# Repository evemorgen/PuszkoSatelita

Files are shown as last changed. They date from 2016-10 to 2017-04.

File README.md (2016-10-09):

# To jest repo w którym trzymamy wszystkie pliki zwiącane z projektem CanSat #

## Struktura organizacyjna: ##
1. dokumentacja
    - folder *dokumentacja* służy do trzymania dokumentacji projektu, kolejnych jej iteracji, oraz ostatecznych wersji na PDR, CDE, FDR
2. code
    - folder *code* służy do trzymania jakiegokolwiek kodu, czy to arduino czy coś co będzie obrabiać dane potem itd.
3. elektronika
    - folder *elektronika* służy do trzymania schematów eagle dla projektu, ewentualnie innych dziwnych rzeczy związanych z elektroniką.

## Media społecznościowe ##
  * [Facebook](https://www.facebook.com/JJCanSatTeam/)

  * [WordPress](https://jjcansat.wordpress.com)

And remember, before asking     
<p align="center">
    
</p>

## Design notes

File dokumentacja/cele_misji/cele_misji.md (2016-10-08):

## Cel podstawowy
  - Mierzenie temperatury i ciśnienia oraz wnioskowanie wysokości na podstawie pomiarów.

## Cele dodatkowe
  - Zebranie i przetworzenie informacji na temat warunków do lądowania ciężkiego lądownika na badanym obszarze.

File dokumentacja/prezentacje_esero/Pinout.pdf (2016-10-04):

Mapa wyjść komputera pokładowego Arduino Pro Micro

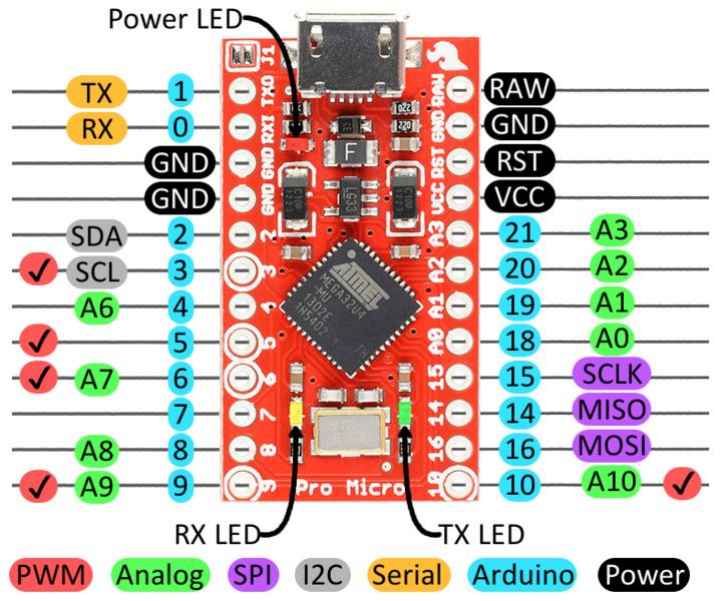
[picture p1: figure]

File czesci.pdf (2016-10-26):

CZĘŚĆ | CENA | Link | UWAGI
Rasberry Pi Zero | 10Phound ~ 50zł + 5phound wysyłka | https://thepihut.com/products/raspberry-pi-zero
Termometr | 23,9 | https://botland.com.pl/czujniki-temperatury/3144-czujnik-temperatury-wysokiej-precyzji-mcp9808-i2c-modul-adafruit.html
Enkoder optyczny (czujnik prędkości wiatru) | 29,9 | https://botland.com.pl/enkodery/1878-zestaw-enkoderow-optycznych-do-micro-silnikow-pololu-wersja-33v.html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
Pololu AltlMU-10 v5 | 89,9 | https://botland.com.pl/czujniki-9dof-imu/5728-pololu-altimu-10-v5-zyroskop-akcelerometr-kompas-i-wysokosciomierz-i2c-3-5v.html
Waveshare IMU 10DoF | 64 | https://botland.com.pl/czujniki-9dof-imu/4655-waveshare-imu-10dof-mpu9255-bmp180-3-osiowy-akcelerometr-zyroskop-i-magnetometr-oraz-barometr.html
GPS | 197 | https://botland.com.pl/moduly-gps/1691-odbiornik-gps-venus-ze-zlaczem-sma-sparkfun.html
Antena do GPS | 57 | https://botland.com.pl/anteny/2315-antena-gps-embedded-ze-zlaczem-sma.html?search_query=gps+antena&results=25
Kamera Pi zero | 135 | http://allegro.pl/wawa-kamera-v2-8mpx-do-wyboru-do-raspberry-pi-3b-i6304136630.html
Baterie Li-Ion | 103,6 | https://botland.com.pl/akumulatory-li-ion/5658-ogniwo-18650-li-ion-panasonic-ncr-18650b-3400mah.html
Przetwornica 3.3V | 47,8 | https://botland.com.pl/przetwornice-impulsowe/1427-przetwornica-step-up-step-down-s7v8f3-5v-1a.html
Elementy pasywne (filtracja) | ~10 | pojedyńczo w sklepach
Radio RF | $12.72 | http://www.ebay.com/itm/331962516696

Stacja bazowa
Arduino Uno Rev3 (wstawiam orginał) | 95 | https://botland.com.pl/arduino-moduly-glowne/1060-arduino-uno-r3.html
Radio RF | $12.72 | http://www.ebay.com/itm/331962516696
Antena Yagi | 152 | http://allegro.pl/antena-lte-800-1800-mhz-b315-b593-zte-d-link-sma-i5985534928.html
moduł microSD | 14,9 | https://botland.com.pl/akcesoria-do-kart-pamieci/5631-modul-czytnika-kart-microsd-waveshare.html
kabel do kompa | 4,19 | https://nettigo.pl/products/kabel-usb-a-b?utm_campaign=all_akademia&utm_medium=link&utm_source=mcart
kabel do anteny | 10 m w zestawie z anteną | http://allegro.pl/antena-lte-800-1800-mhz-b315-b593-zte-d-link-sma-i5985534928.html

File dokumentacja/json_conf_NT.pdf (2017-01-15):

# JJ CanSat Team Base Station JSON protocol

## "Message type" : (String)

Indicates what is in the frame.
- "STANDARD_DATA" – standarized sensors measurements.
- "ERROR" : - information about error.
- "CONF_REQUEST" – message aimed to obtain configuration data.

## Standard data

- "TEMP_CAN" : Temperature measured by CanSat. (Float)
- "TEMP_BASE" : Temperature measured by Base Station. (Float)
- "PRESS_CAN" : Pressure measured by CanSat. (Float)
- "PRESS_BASE" : Pressure measured by Base Station. (Float)
- "X_ROT" : X axis CanSat rotation. (Float)
- "Y_ROT" : Y axis CanSat rotation. (Float)
- "Z_ROT" : Z axis CanSat rotation. (Float)
- "ALT_BASE" : Altitude measured by Base Station. (Float)
- "GPS_N" : N GPS CanSat cordinate. (Float)
- "GPS_E" : E GPS CanSat cordinate. (Float)
- "WIND_SPEED": Wind speed measured by CanSat. (Float)
- "AIR_HUM": Air humidity measured by CanSat. (Float)

## Error

- "ERROR_TYPE" : Information about occured error. (String)

## Example frame

{
"Message type" : "STANDARD_DATA", "TEMP_CAN" :1,
"TEMP_BASE" : 1,
"PRESS_CAN" : 1,
"PRESS_BASE" :1,
"X_ROT" : 1,
"Y_ROT" : 1,
"Z_ROT" :1,
"ALT_BASE" :1,
"GPS_N" : 1,
"GPS_E" : 1,
"WIND_SPEED": 1,
"AIR_HUM": 1
}

{
"Message type" : "ERROR",
"ERROR_TYPE" : "SDCARD_ERROR" }

{
"Message type" : "CONF_REQUEST" }

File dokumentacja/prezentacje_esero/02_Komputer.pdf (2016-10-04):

## I sesja technologiczna

# Komputer pokładowy

WARSZTATY CANSAT

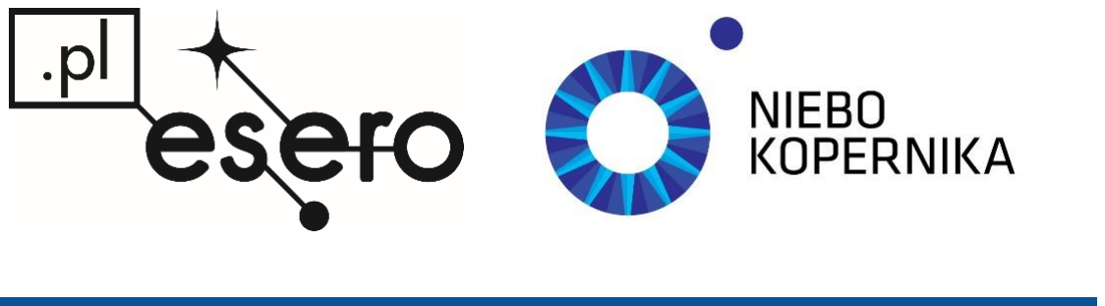
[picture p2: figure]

## Komputer pokładowy Arduino Pro Micro

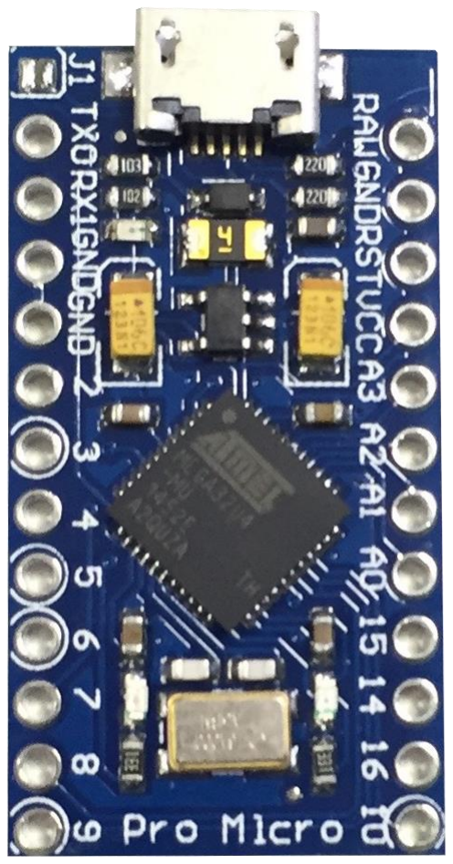
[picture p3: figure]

- mikrokontroler ATMega32U4
- bootloader Arduino
- port microUSB: (programowanie + serial port + zasilanie)
- wyprowadzone piny procesora (m.in. GPIO, ADC, SPI, I2C, UART) + zasilanie
- https://www.sparkfun.com/products/12640 (https://www.sparkfun.com/products/12640)

# Mózg CanSata – ATMega 32U4

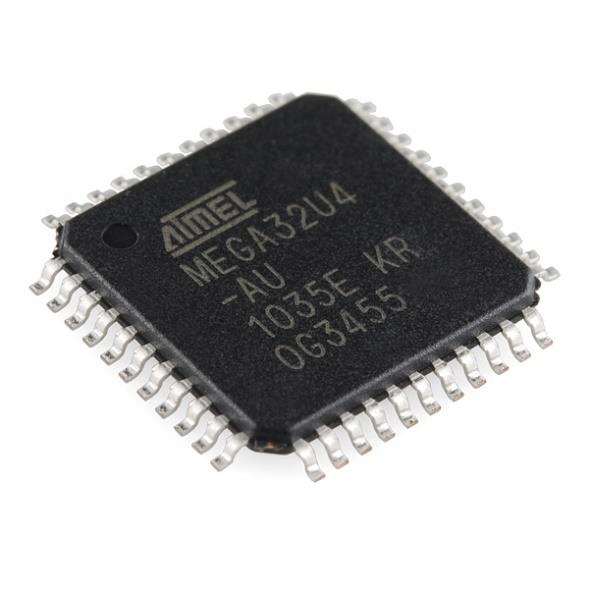
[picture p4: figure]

- programowalny mikrokontroler
- AVR, 8-bit
- 32K pamięci FLASH programu
- 2.5K pamięci SRAM
- 1K pamięci EEPROM

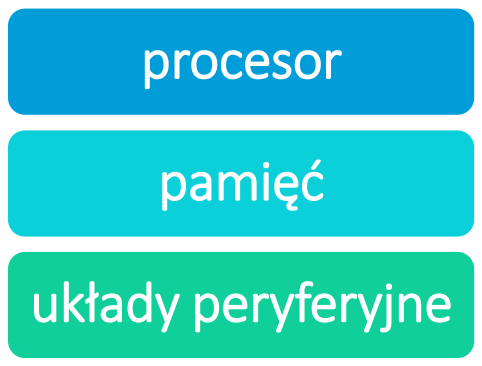
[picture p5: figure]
procesor; pamięć; układy peryferyjne

- Układy peryferyjne:
- 26 x GPIO
- 12 x 10-bit ADC
- UART
- 2x SPI, I2C
- USB

# Złącza komputera pokładowego

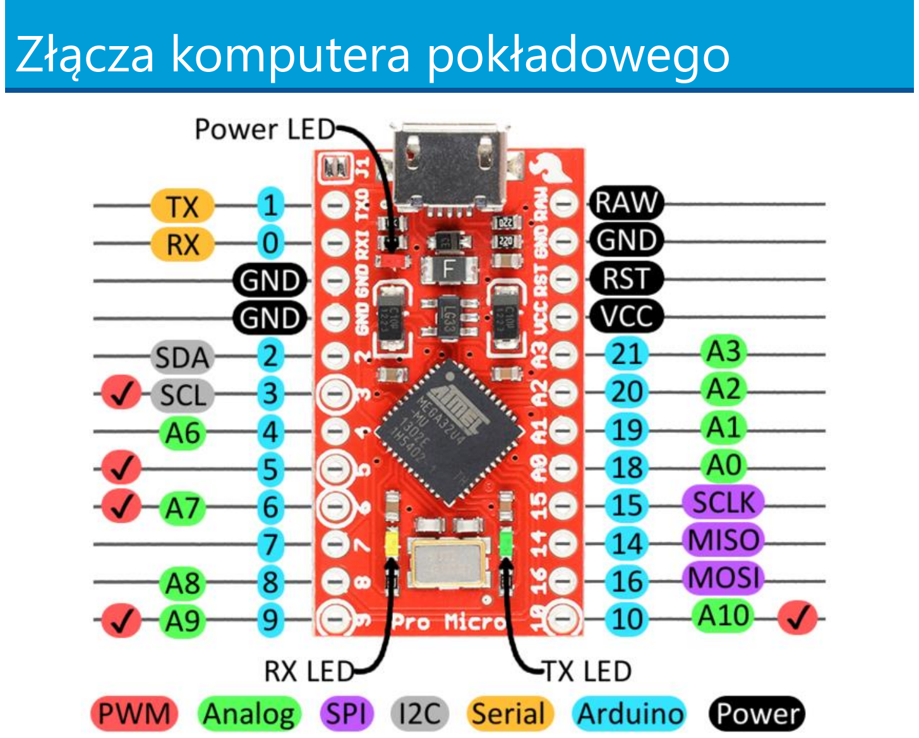
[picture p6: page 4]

# Programowanie

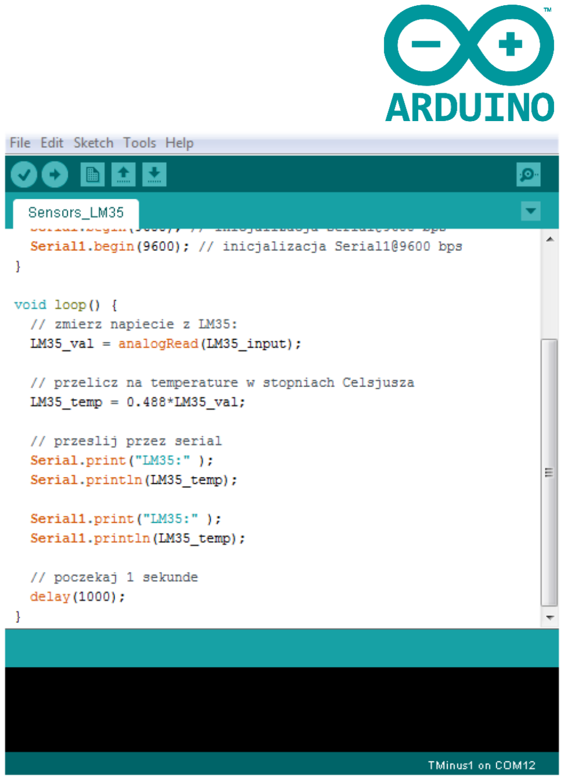
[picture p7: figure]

- C / C++
- Arduino IDE, Atmel
Studio...
- zgodność z platformą
Arduino
- liczne biblioteki
- mnogość przykładów i
tutoriali dotyczących
programowania

# Uruchomienie płytki

1. Instalacja sterowników do płytki komputera pokładowego

https://learn.sparkfun.com/tutorials/pro-micro--fio-v3-hookup-guide/installing-windows

2. Płytka widoczna w Menedżerze urządzeń
3. Instalacja Arduino IDE (wersja 1.6.4 lub wyższa)
4. Instalacja płytki komputera pokładowego w Arduino IDE

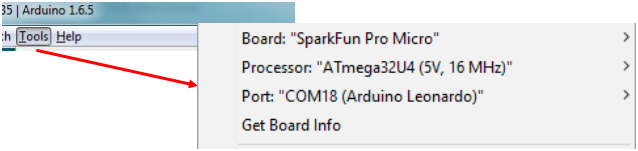
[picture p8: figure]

# Uruchomienie płytki

4. Instalacja płytki komputera pokładowego w Arduino IDE:

### - otwieramy okno File > Preferences

### - w polu “Additional Board Manager URLs” wpisujemy:

https://raw.githubusercontent.com/sparkfun/Arduino_Boards/master/IDE_Board_Manager/package_sparkfun_

index.json

# Uruchomienie płytki

4. Instalacja płytki komputera pokładowego w Arduino IDE:

### - otwieramy Tools > Board: „xxx” > Board Manager

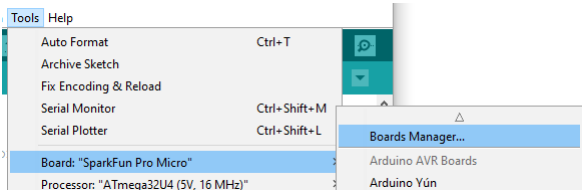
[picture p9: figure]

### - szukamy SparkFun AVR Boards

### - klikamy Install

# Uruchomienie płytki

4. Instalacja płytki komputera pokładowego w Arduino IDE:

### - wybieramy płytkę Tools > Board > „SparkFun Pro Micro”

### - wybieramy procesor ATMega32U4 (5V, 16 MHz)

### - wybieramy port wg wskazań Menedżera urządzeń

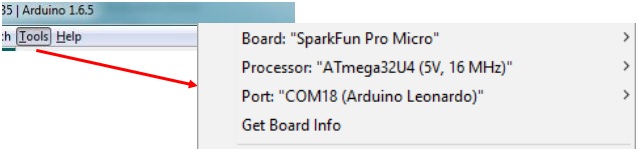
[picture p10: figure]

### Płytka jest gotowa do pracy!

# Wgrywanie pierwszego programu

- otwórz plik „HelloCanSat.ino” z katalogu „CanSat 2017” na Pulpicie
- skompiluj i wgraj do procesora:
- obserwuj działanie!

## Gdzie jesteśmy?

✓ zainstalowane sterowniki do płytki

✓ skonfigurowane środowisko programistyczne

✓ działająca, przetestowana płytka komputera pokładowego

# Komunikacja przez Serial port (UART)

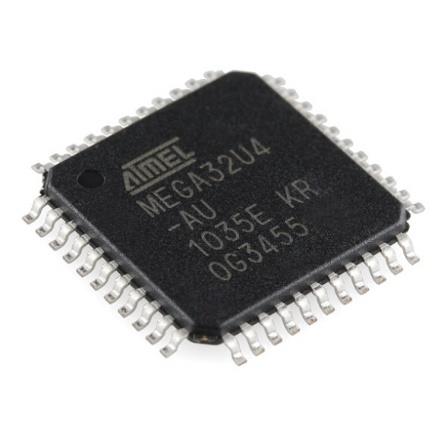
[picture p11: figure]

- szybki, dwukierunkowy interfejs komunikacji
- inicjalizacja:
Serial.begin(9600);
- wysyłanie danych:
Serial.print(„Hello world”);
- odbieranie danych:
Serial.read();

Serial

microUSB

komputer

# Komunikacja przez Serial port (UART)

void setup() {
Serial.begin(9600); // inicjalizacja z prędkością 9600bps }

void loop() {
Serial.print(”Warsztaty CanSat ”); | // wypisz tekst
Serial.println(2017); | // wypisz liczbę
delay(1000); | // poczekaj 1 s
}

# Komunikacja przez Serial port (UART)

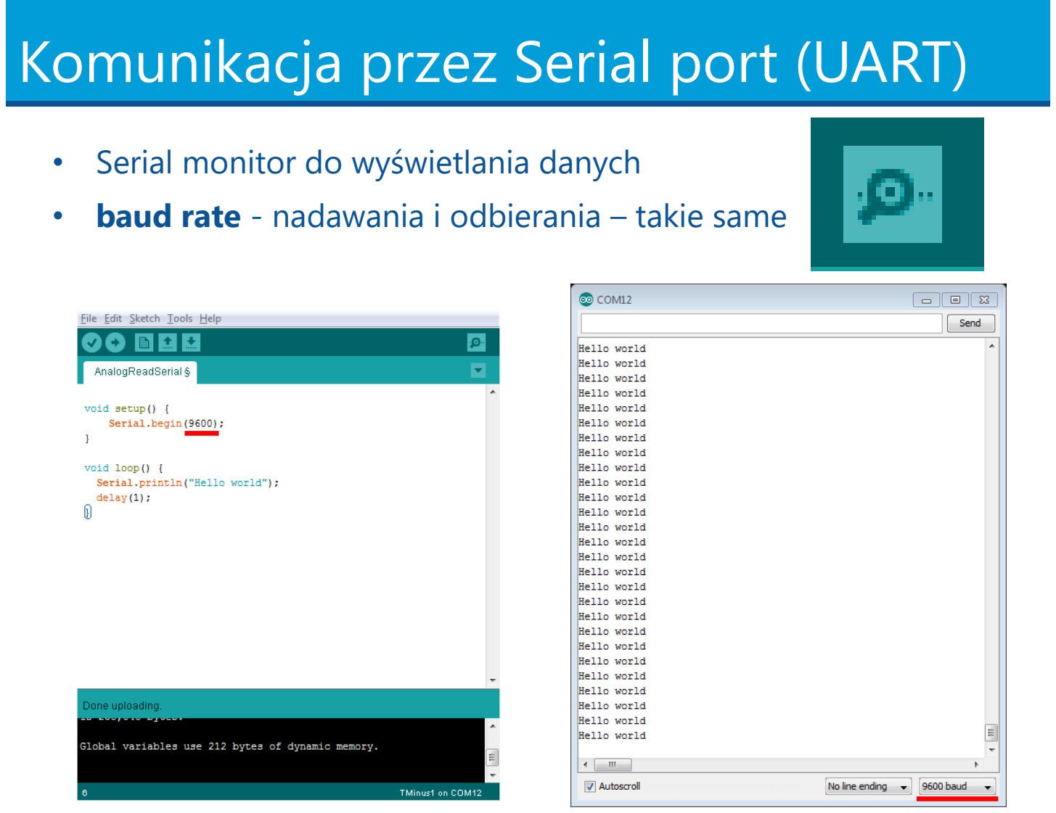
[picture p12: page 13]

- Serial monitor do wyświetlania danych
- baud rate - nadawania i odbierania – takie same

# GPIO – wyjścia cyfrowe

- 18 pinów
- dwa stany:
- HIGH – logiczne „1” – napięcie 5 V
- LOW – logiczne „0” – napięcie 0 V
- użycie:

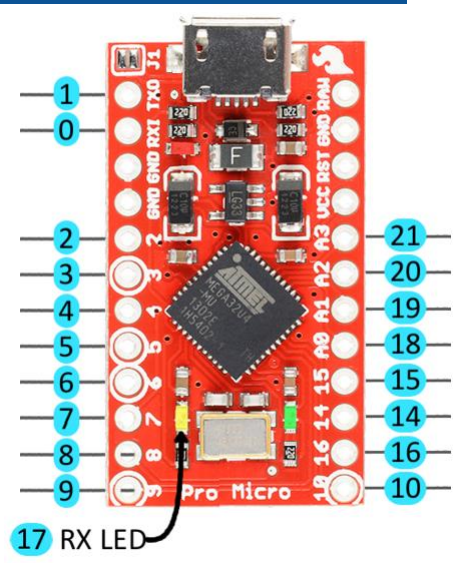
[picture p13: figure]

- inicjalizacja: pinMode(numer, OUTPUT);
- zmiana stanu: digitalWrite(numer, stan);

# GPIO – wyjścia cyfrowe – miganie diodą

- dioda LED (RX), podłączona do pinu 17

void setup() {
pinMode(17, OUTPUT); // GPIO w trybie wyjścia }

void loop() {
digitalWrite(17, HIGH); // LED świeci
delay(1000); | // poczekaj 1 s
digitalWrite(17, LOW); | // LED nie świeci
delay(1000); | // poczekaj 1 s
}

# GPIO – wejścia cyfrowe

- 18 pinów
- wykrywają dwa stany:
- HIGH – logiczne „1” – napięcie 5 V
- LOW – logiczne „0” – napięcie 0 V
- użycie:
- inicjalizacja: pinMode(numer, INPUT);
- odczytanie stanu:

bool stan = digitalRead(numer);

# GPIO – wejścia cyfrowe + Serial

- wysyłanie stanu wejścia cyfrowego na port Serial
- sprawdź działanie łącząc wejście raz z GND (0 V), następnie z 5 V

void setup() {
pinMode(0, INPUT); | // GPIO w trybie wejścia
Serial.begin(9600); | // inicjalizacja Serial
}

void loop() {
bool stan = digitalRead(0); | // odczytaj stan
Serial.println(stan); | //wyślij stan
delay(1000); | // poczekaj 1 s
}

# Wejścia analogowe (ADC)

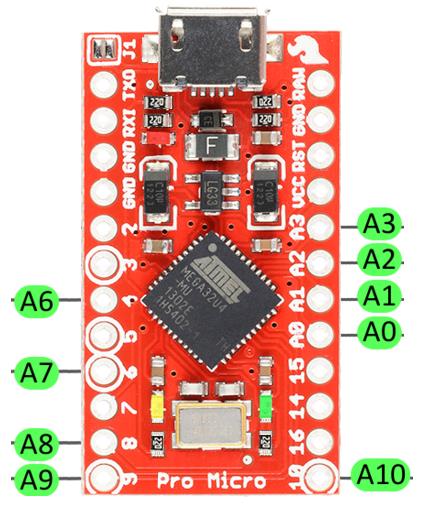
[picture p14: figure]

- mierzą napięcie z przedziału 0 – 5 V
- rozdzielczość 10 bit
- LSB = 4,88 mV
- 9 pinów, oznaczone jako Ax
- użycie:
- odczytanie wartości:

int value = analogRead(Ax);

(zwracana wartość: 0 – 1023 LSB)
- przeliczenie LSB na napięcie:

napięcie_mV = LSB * 4,88

# Wejścia analogowe (ADC) + Serial

- wysyłanie stanu wejścia analogowego na port Serial
- sprawdź działanie łącząc wejście z GND (0 V), 1.5 V, 5 V.

void setup() {
Serial.begin(9600); | // inicjalizacja Serial
}

void loop() {
int value = analogRead(A0); | // odczytaj stan
float miliwolt = value*4.88; | // przelicz na mV

Serial.print(”LSB = ”);
Serial.println(value);

Serial.print(”mV = ”);
Serial.println(miliwolt);
delay(1000); | // poczekaj 1 s
}

# Biblioteki qbcan

Instalacja bibliotek do obsługi czujników i modułu radiowego:

1. W Arduino IDE: Sketch > Include Library > Add .ZIP Library…
2. Wybieramy plik Qbcan.zip

Biblioteka pozwala na obsługę czujnika ciśnienia BMP180 oraz modułu radiowego RFM69HW.

3. Bibliotekę dołączamy za pomocą dyrektywy #include:

#include <qbcan.h>

# Podsumowanie

### Po tej sesji mamy:

### - przetestowany i działający komputer pokładowy

### - uruchomioną komunikację z komputerem PC

### - opanowane podstawowe urządzenia peryferyjne

### - zainstalowane biblioteki do obsługi czujników i radia

Q&A

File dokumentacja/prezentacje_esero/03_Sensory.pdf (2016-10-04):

II sesja technologiczna

# Sensory

WARSZTATY CANSAT


Sensory (czujniki) - przetworniki wielkości nieelektrycznych na elektryczne np. temperatura na napięcie.

## Sensory - czyli jak rozpoznać środowisko

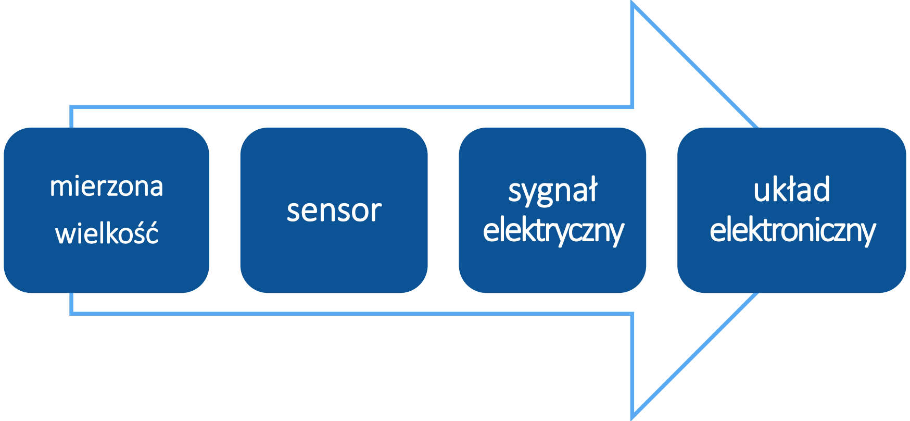
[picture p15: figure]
mierzona; wielkość; sensor; sygnał elektryczny; układ elektroniczny

## Podstawowa charakterystyka sensorów

- zakres pomiarowy
- rozdzielczość
- dokładność
- szybkość akwizycji
- szybkość odpowiedzi

## Mnogość wyboru

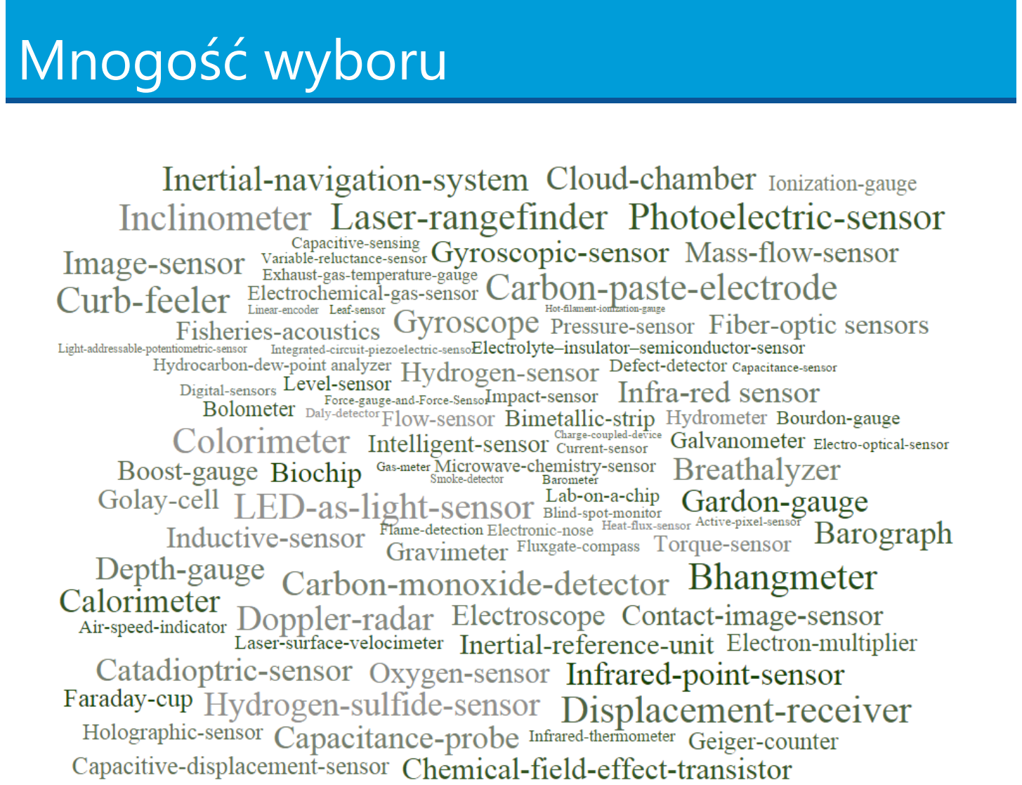
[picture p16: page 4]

## Rodzaje pomiarów

czujnik temperatury | temperatura
czujnik ciśnienia | ciśnienie

### temperatura ciśnienie

## wysokość

Pomiary bezpośrednie

Pomiary pośrednie

## Wybór właściwego elementu

| oczekiwane parametry | czujnik temperatury LM35 | ok?
zakres pomiarowy | 5 – 50 °C | 2 – 150 °C (-55 – 150 °C – ujemne napięcie zasilania) | ✔
dokładność | ± 1 °C | ± 0.5 °C @ 25 °C | ✔
rozdzielczość | ± 1 °C | zależne od reszty układu | ?
częstotliwość odczytu | 1 Sample/s | zależne od reszty układu | ?
napięcie zasilania | 4,5 – 5,5 V | 4 – 30 V | ✔
sygnał wyjściowy | analogowy: 0-5 V | analogowy, 10 mV/°C (w wymaganym zakresie: 0 – 500 mV) | ✔
cena | < 20 PLN | ok. 10 PLN | ✔

## Sensor w zestawie CanSat

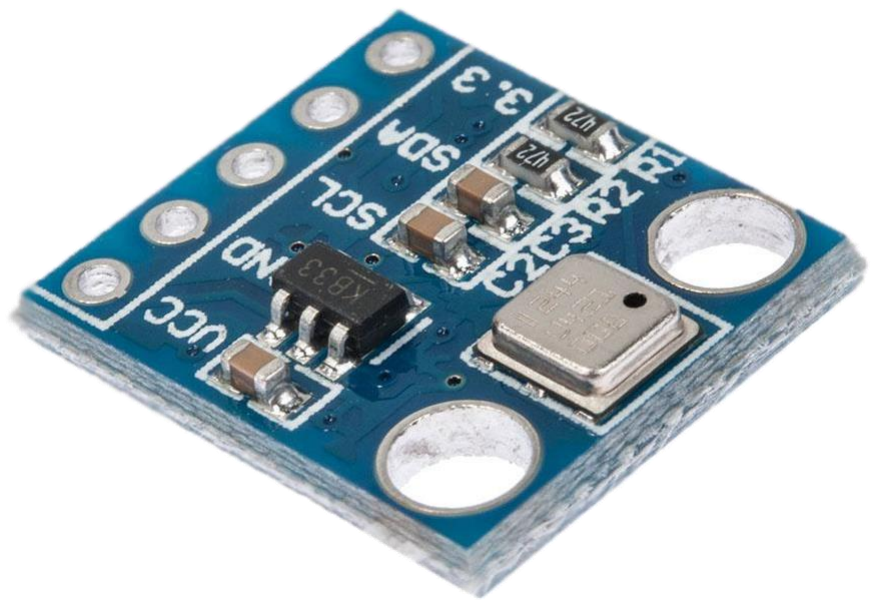
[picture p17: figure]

temperatura | + | ciśnienie atmosferyczne

## BMP 180

| Bosh

## Magistrala I²C

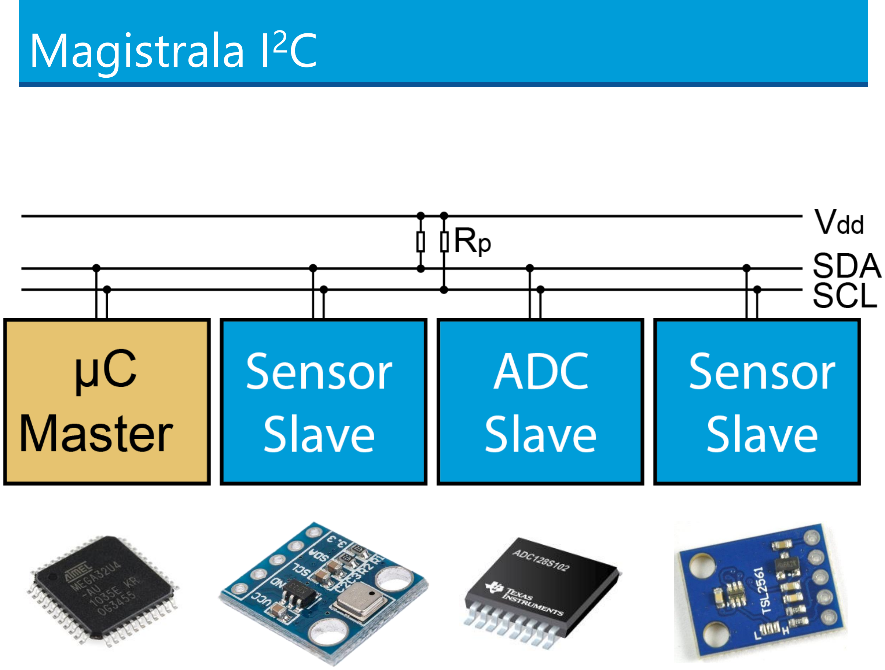
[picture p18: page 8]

## Konwerter poziomów logicznych

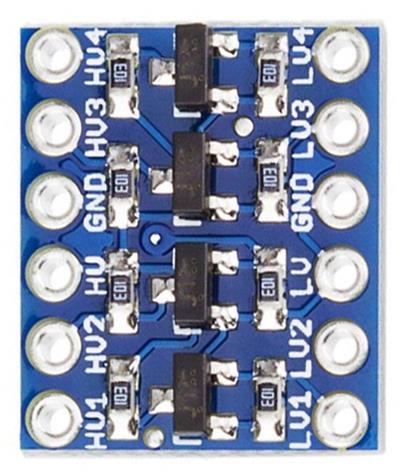
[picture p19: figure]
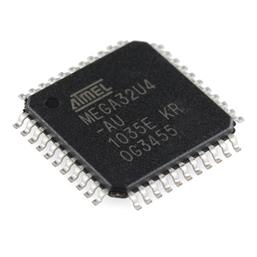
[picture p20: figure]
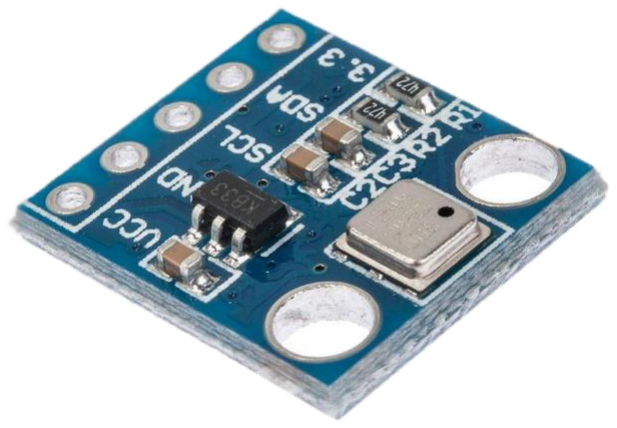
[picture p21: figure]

5 V | 3.3 V

## Pomiar temperatury

- rozdzielczość pomiaru temperatury ~ 0,1 ℃
- dokładność czujnika 2 ℃ @ (0 ÷ 65 ℃)

## Pomiar ciśnienia

- rozdzielczość pomiaru ciśnienia ~ 0,01 ℎPa
- dokładność czujnika −6 ÷ +4.5 ℎPa @ (−20 ÷ 0 ℃)

−4 ÷ +2 ℎPa @ (0 ÷ 65 ℃)

## BMP180 – oprogramowanie

Dołączenie potrzebnej biblioteki:

#include <qbcan.h>

Utworzenie obiektu czujnika:

BMP180 bmp;

Metoda begin inicjalizuje czujnik, zwraca true jeśli się powiodła

bmp.begin()

Metoda do odczytywania pomiaru – temperatura, ciśnienie

bmp.getData(T, P);

## BMP180 – wyświetlanie pomiarów

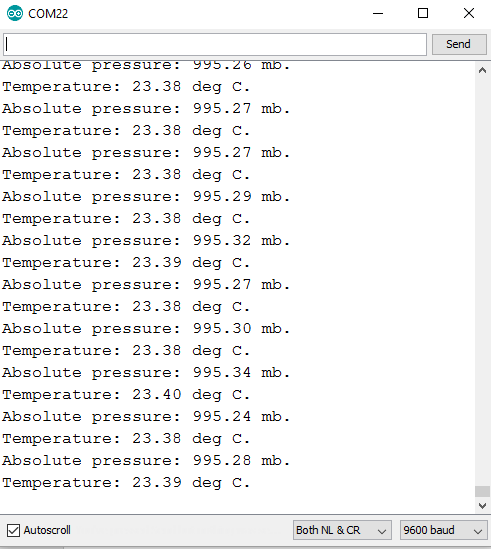
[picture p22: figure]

## Analogowy czujnik temperatury LM35

- czujnik analogowy

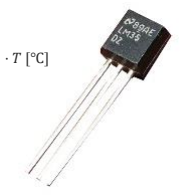
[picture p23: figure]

- liniowa zależność UWY T = 10 | mVΤ℃ | ⋅ T [℃]
- rozdzielczość pomiaru napięcia ≈ 4,88 mV
- daje to ~ 0,5 ℃ rozdzielczości
- dokładność czujnika 0,5 ℃ @ 25 ℃

## Czujniki analogowe vs. cyfrowe

Drużyny mają pełną dowolność w wyborze modeli czujników także tych do misji podstawowej!

## analogowe

- uproszczone
oprogramowanie
- łatwiejsze debugowanie

## cyfrowe

- bardziej odporne na szumy
- wiele czujników na jednej magistrali
- bardziej skomplikowane
oprogramowanie

## Przetwarzanie danych

- mniej obróbki danych na procesorze CanSata = lepiej
- „NIE” dla obliczeń zmiennoprzecinkowych
- np.: wysokość (h) obliczana ze wzoru barometrycznego:

p = p0 ⋅ exp −

μgℎ
RT

p0 – ciśnienie atmosferyczne na poziomie odniesienia,

μ – masa molowa powietrza (0,0289644 kg/mol),

g – przyspieszenie ziemskie,

R – stała gazowa,

T – temperatura powietrza w K

(źródło: https://pl.wikipedia.org/wiki/Wz%C3%B3r_barometryczny)

## Analiza danych

- Co mówią zebrane dane?
- Dopasowanie przewidywań teoretycznych / modelu
- Określenie poprawności danych
- Jak najlepiej przedstawić zebrane dane?
– tabela | – wykres
- Wykresy:
– dane w funkcji czasu: np. T(t), h(t)

– dane w funkcji danych np. T(h)

## Obróbka i wizualizacja danych

- Pakiety biurowe np. LibreOffice, MS Office itp.
- GNUPlot
- Python + matplotlib
- LabVIEW
- Matlab

## Jak narysować dobry wykres?

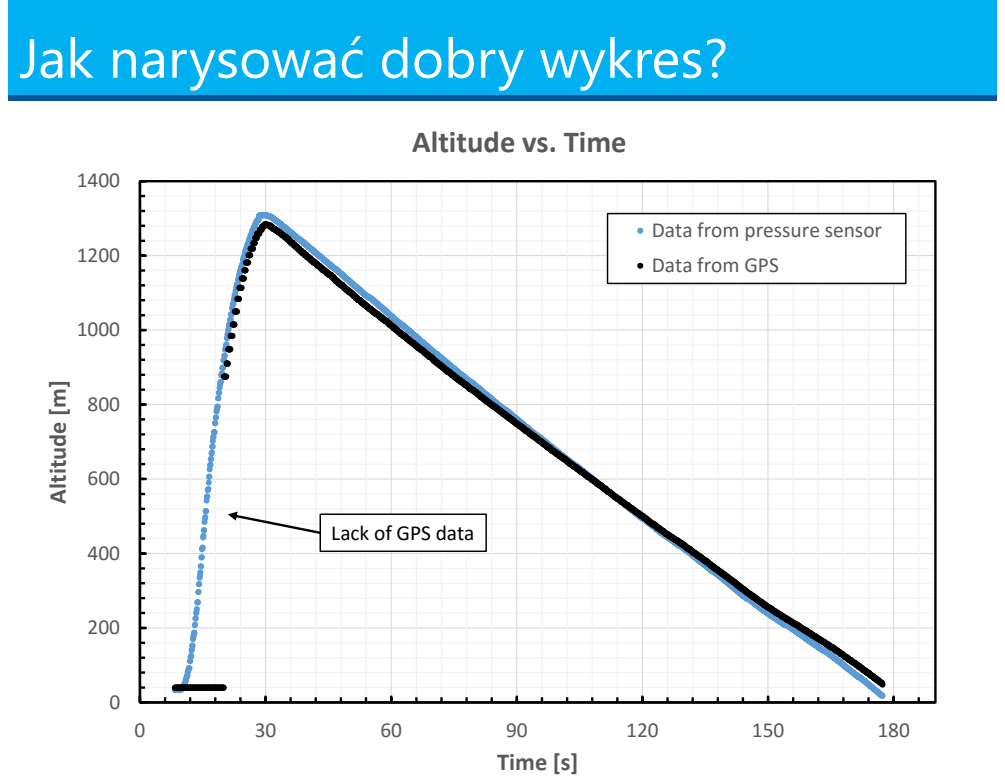
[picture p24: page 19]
Altitude [m]; Time [s]

Altitude vs. Time

Data from pressure sensor
Data from GPS

Lack of GPS data

## Jak narysować dobry wykres?


Q&A

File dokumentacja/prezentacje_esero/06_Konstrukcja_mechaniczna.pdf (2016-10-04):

# Konstrukcja mechaniczna

WARSZTATY CANSAT


# Wymiary i masa


CanSat | spadochron, anteny (giętkie)

masa: 300 – 350 g (jeśli jest lżejszy musi wziąć balast! – wymaga miejsca!)

115 | 40

# Obudowa


# Obudowa


- chroni podzespoły przed wilgocią, deszczem, a także pyłem
- chroni wnętrze CanSata przed uszkodzeniem w trakcie lądowania
- spadochron powinien być
przymocowany do wewnętrznej struktury!
- jest łatwo zdejmowalna!

# Obudowa, a łatwość dostępu


OBUDOWA POWINNA POZWALAĆ
NA:
- wymianę baterii zasilających
- łatwą wymianę akumulatorów (nawet jeśli mają być ładowane
w CanSat)
- dojście do kill-switcha (włącznika głównego) dla obsługi
konkursu/organizatorów !


- programowanie częstotliwości / kanału transceiverów

# System odzyskiwania - wymagania


- po złożeniu spadochron może zajmować maksymalnie przestrzeń ograniczoną walcem o średnicy 66 mm i wysokości 40 mm
- szybkość opadania: 6 – 11 m/s
- mocowanie spadochronu do CanSatu musi wytrzymać siłę 1000 N
- każda linka powinna wytrzymać siłę
ൗ

1000
Nlinek [N]

# Projektowanie spadochronu


- kluczowe jest osiągnięcie zakładanej szybkości opadania
- spadochron powinien zachowywać stabilność spadania

Fizyka spadochronu

- po pewnym (krótkim) czasie siła oporu równoważy ciężar całego układu (Fo = Fg), a szybkość opadania stabilizuje się
- w dużym uproszczeniu: vmax(m, S)

# Projektowanie spadochronu

- Jaka średnica?

gdzie:
S – powierzchnia spadochronu
v – szybkość powietrza opływającego spadochron mc

, ms
- masa cansatu, spadochronu g – przyśpieszenie ziemskie
ρ – gęstość powietrza
Cd – bezwymiarowy współczynnik czołowego oporu aerodynamicznego, zależny od kształtu obiektu

൞

### Fg = (mc + ms) ⋅ g

Fo =

1
2

⋅ v

2

### ⋅ S ⋅ Cd ⋅ ρ

S =

### 2 ⋅ mc + ms

⋅ g
v

### 2 ⋅ Cd ⋅ ρ

Tabela współczynników Cd
kwadrat | 1,000
sześciokąt | 0,866
ośmiokąt | 0,828
koło | 0,785

# Projektowanie spadochronu


- Otwór znacznie poprawia stabilność spadochronu
- Średnica otworu ≈ 20% średnicy spadochronu
- Symulacje np. w Rocksim

# Projektowanie spadochronu


- Przynajmniej 6 linek dla stabilności i redundancji
- Wykonany z nienasiąkalnego i niemnącego się materiału
- Jaskrawy kolor ułatwi znalezienie CanSata po upadku na ziemię

# Testy spadochronu


- Testy wytrzymałościowe
- mocowania
- poszczególnych linek

# Testy spadochronu


- Testy w locie:
- testy otwarcia się spadochronu
- testy szybkości spadania
- duża wysokość
(kilkadziesiąt metrów)

# Połączenia kablowe i wtyczki


Wtyczki i kable, złącza baterii zabezpieczone taśmą izolacyjną!

Najlepiej zastosować
wtyczki z klipsem

Kable zabezpieczyć klejem
uniemożliwiając ruch przy
samym spoiwie

Q&A

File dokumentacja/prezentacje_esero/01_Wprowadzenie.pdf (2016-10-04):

# Wprowadzenie do CanSatów

WARSZTATY CANSAT


# Co to są CanSaty?


## minisatelity?

## sondy kosmiczne?

## symulacja misji kosmicznej

## CanSat – symulacja programu kosmicznego

wyzwanie dla uczniów:

- system zasilania
- komputer pokładowy
- sensory
- system komunikacji
- system odzyskiwania

w małej puszce.

- systemy, które zawiera
każda sonda planetarna

## CanSat – symulacja programu kosmicznego

- wyniesienie CanSatu na
wysokość przynajmniej

### 1 km

- system wynoszenia:
rakieta,
samolot,
balon,
dron

## CanSat – symulacja programu kosmicznego

- organizacja pracy przy
misji kosmicznej
- poszczególne fazy
projektu kosmicznego
- dokumentacja projektu:
Preliminary Design
Review (PDR),
Critical Design Review
(CDR),
Final Design Review (FDR)

# CanSat to także…

- praca zespołowa
- nauka poprzez działanie
- świetna zabawa

# Misje CanSatów

podstawowa

## - pomiar ciśnienia i temperatury - wysyłanie danych drogą radiową raz na sekundę - analiza danych (wysokość od czasu)

dodatkowa

# Sky is not the limit

# Jak zbudowany jest CanSat?


SYSTEM ZASILANIA

KOMPUTER
POKŁADOWY

STRUKTURA
MECHANICZNA

SYSTEM
ODZYSKIWANIA

PAYLOAD (ŁADUNEK UŻYTECZNY)

SENSORY

INNE
URZĄDZENIA
NP. KAMERY

SYSTEM
KOMUNIKACJI

STACJA NAZIEMNA

SYSTEM KOMUNIKACJI

KOMPUTER

# Budowa CanSata to duży projekt

# Jak sobie z tym poradzić?

## drużyna, spotkania, zadania, terminy

# Drużyna i podział obowiązków

- zgrana – oprócz wspólnej pracy ważna jest też integracja
- podział prac w drużynie:
- team leader – koordynuje pracę całego zespołu
- plan misji
- oprogramowanie
- elektronika
- analiza danych
- outreach
- …

# Spotkania

- zazwyczaj praca odbywa się w obrębie każdego elementu projektu (np. sensory, oprogramowanie, mechanika)
- spotkania muszą być organizowane regularnie, ale nie za często np. raz w tygodniu
- Cele spotkań:
- wypracowanie wspólnej strategii
- kontrola postępu prac
- integracja systemów

# Zadaniowy system pracy

duży projekt składa się z małych zadań

realizujemy zadania, nie cały projekt

- aplikacje wspomagające np.: Asana, Redmine, Trello

Metoda:

- zadania są przypisane do konkretnej osoby
- każde zadaniema chociaż przybliżony czas realizacji

# Zadaniowy system pracy


# Fazy projektu

- Wybór celów misji
- Definiowanie wymagań technicznych
- Projektowanie i tworzenie sprzętu oraz oprogramowania
- Udokumentowane rewizje
- Integracja podzespołów i testy CanSatu

# Dokumentacja projektu

Trzy rewizje postępu:

- Preliminary Design Review (PDR),
- Critical Design Review (CDR),
- Final Design Review (FDR)

Drużyny otrzymają feedback i wskazówki na podstawie każdego przedstawionego dokumentu.

zobacz: https://en.wikipedia.org/wiki/Design_review_(U.S._government)

# Dokumentacja projektu - PDR

PDR jest rewizją techniczną, która ma zapewnić zespół, że obecny kształt projektu pozwala na jego kontynuację, tak aby w następnym kroku osiągnął zaawansowany etap rozwoju, a końcowe rezultaty będą mogły spełniałnić wszelkie założenia.

### CanSat PDR powinien zawierać:

- pokazanie, że wszystkie warunki stawiane w dokumencie „Wytyczne” zostaną spełnione
- przedstawienie misji dodatkowej
- specyfikację projektową w celu zrobienia misji dodatkowej
- wstępny budżet
- zarys dat kluczowych dla projektu

# Dokumentacja projektu - CDR

CDR jest rewizją techniczną, która ma zapewnić zespół, że obecny kształt projektu pozwala na jego kontynuację, tak aby końcowe rezultaty spełniały wszelkie poczynione założenia. CDR szczegółowo podsumowuje projekt CanSata, określa gotowość do produkcji sprzętu i pisania oprogramowania. Określa również ostateczną konfigurację misji dodatkowej.
CDR jest zmodyfikowaną wersją PDR. Dokument ten powinien zawierać wszelkie różnice względem PDR, jak również opis dokonanego postępu technicznego. Dodatkowo w dokumencie powinna być zawarta najważniejsza z punktu widzenia projektu dokumentacja oraz rewizję dotychczasowych planów.

### CanSat CDR powinien zawierać:

- Postępy względem PDR
- Przegląd zadań misji
- Zaktualizowany budżet
- Zaktualizowany zarys poszczególnych etapów i terminów

# Dokumentacja projektu - FDR

FDR jest końcowym raportem, który powinien być wysłany PRZED kampanią startową. Raport zawiera wszystkie zmiany wprowadzone do projektu (w porównaniu do CDR) oraz ich implementacje. Dokument powinien dokładnie opisać wszystkie szczegóły gotowego CanSata.
Będzie to główny dokument dostarczony do oceny przez Jury, którego zadaniem podczas kampanii startowej będzie będzie ocena pracy każdego zespołu.

### CanSat FDR powinien zawierać:

- zmiany od wersji przedstawionej w CDR
- opis wszelkich szczegółów gotowego CanSata

# Dokumentacja projektu - struktura

PROGRESS REPORT

i. New progress statement for team profile

ii. Task list

iii. Detailed project status

# Dokumentacja projektu - struktura

DESIGN DOCUMENT

1 INTRODUCTION

1.1 Team organization and roles

1.2 Mission objectives

2 CANSAT DESCRIPTION

2.1 Mission overview

2.2 Mechanical/ structural design

2.3 Electrical design

2.4 Software design

2.5 Recovery system

2.6 Ground support Equipment

# Dokumentacja projektu - struktura

3 PROJECT PLANNING

3.1 Time schedule of the CanSat preparation

3.2 Resource estimation

3.2.1 Budget

3.2.2 External support

3.3 Test plan

4 OUTREACH PROGRAMME

5 REQUIREMENTS

APPENDIX 1 THE CANSAT REQUIREMENTS

Q&A

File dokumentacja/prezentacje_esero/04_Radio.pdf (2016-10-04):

## III sesja technologiczna

# Komunikacja radiowa

WARSZTATY CANSAT


# Transceivery

- Pasmo ISM 424-510 MHz

•Modulacje: FSK, GFSK, MSK,

GMSK, OOK

- Moc 100 mW (20 dBm)
- Czułość -120 dBm
- Komunikacja z komputerem


pokładowym przez magistralę SPI

•Programowanie parametrów przez komputer pokładowy

- Dołączona biblioteka do komputera pokładowego

# Frequency shift keying

Dane wysyłane do transceivera – dane binarne

„Hello world”

01001000 01100101 01101100 01101100 01101111 00100000 01110111 01101111 01110010 01101100 01100100


# Ustawienia transceiverów

Parametry do ustalenia:
1. Carrier frequency
2. Network ID
3. Node ID

# Częstotliwość nośna


- Drużyna musi używać częstotliwości przyznanej przez organizatorów !

# Network & Node ID


# Anteny

- Odpowiednio dobrana antena zwiększa zasięg transceiverów
- Antena w CanSat: monopol - kabel o długości ¼ λ ≈ 17 cm
- Antena w stacji naziemnej: zalecane użycie anteny typu Yagi


- Łatwa w budowie / tania w zakupie
- Zysk rzędu 10 dBi

# Anteny – podłączenie


- Antena w CanSat –
elastyczna, przylutowana bezpośrednio do transceivera
- Powinna wystawać na zewnątrz obudowy CanSata
- Najlepiej od góry / dołu
- Należy uważać na przypadkowe ekranowanie, które zmniejszy zasięg

# Anteny – podłączenie

- Antena dla stacji naziemnej – najlepiej wykorzystać złącze SMA


- Można przylutować kabel koncentryczny bezpośrednio do PCB


ekran

kabel środkowy
(ang. core)

# Zasięg

- Komunikacja może zostać przerwana!
- Bardzo często komunikacja zawodzi przy ziemi - strefa Fresnela


- Szacowanie zasięgu
- Testy zasięgu

# Bilans łącza radiowego


- Oszacowanie zasięgu systemu radiowego

+ 5

- 4
+ 20 dBm

~ -110 @ 3km

+ 5

- 2
- 86 dBm
- 120 dBm

# Testy zasięgu

- Sprawdzenie zasięgu systemu radiowego
- Warunki – widoczność, strefa Fresnela


# Przepustowość

- Przepływność łącza: 1200 bps
- np. 240 pomiarów z wejścia analogowego na sekundę

(kodowanie ASCII, znaki nowej linii)

# Połączenie z komputerem pokładowym

- Wysłanie danych przez
transceiver:

RFM69 radio;


radio.initialize(FREQUENCY, NODEID, NETWORKID);

radio.setFrequency(…);

radio.setHighPower();

radio.send(GATEWAYID, “test”, 4);

- Wyślijmy dane z uruchomionych wczoraj sensorów - bezprzewodowo

# Stacja naziemna – odbieranie danych

- Identyczny komputer i radio!

RFM69 radio;

radio.initialize(FREQUENCY, NODEID, NETWORKID);

radio.setFrequency(…);

radio.setHighPower();


void loop()
{
if (radio.receiveDone())
{
for (byte i = 0; i < radio.DATALEN; i++) Serial.print((char)radio.DATA[i]);
}
}

# Zapis odbieranych danych na dysk

- Serial monitor Arduino jest wystarczający do szybkiego „spojrzenia” na port
- Nie nadaje się do przechwytywania większych ilości danych
- Alternatywy np.: RealTerm/TeraTerm


# Zapis odbieranych danych na dysk


# Inne transceivery i moduły radiowe


Dozwolone są inne moduły, transmitery TV itp. pod następującymi

warunkami:

- są zgodne z obowiązującymi przepisami w Polsce i kraju

rozgrywania zawodów międzynarodowych

- nie zakłócają prawidłowej pracy innych CanSatów (interferencje…)

Q&A

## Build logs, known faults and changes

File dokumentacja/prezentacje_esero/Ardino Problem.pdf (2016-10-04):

# Rozwiązanie problemu braku portu COM

WARSZTATY CANSAT


## Przyczyna:

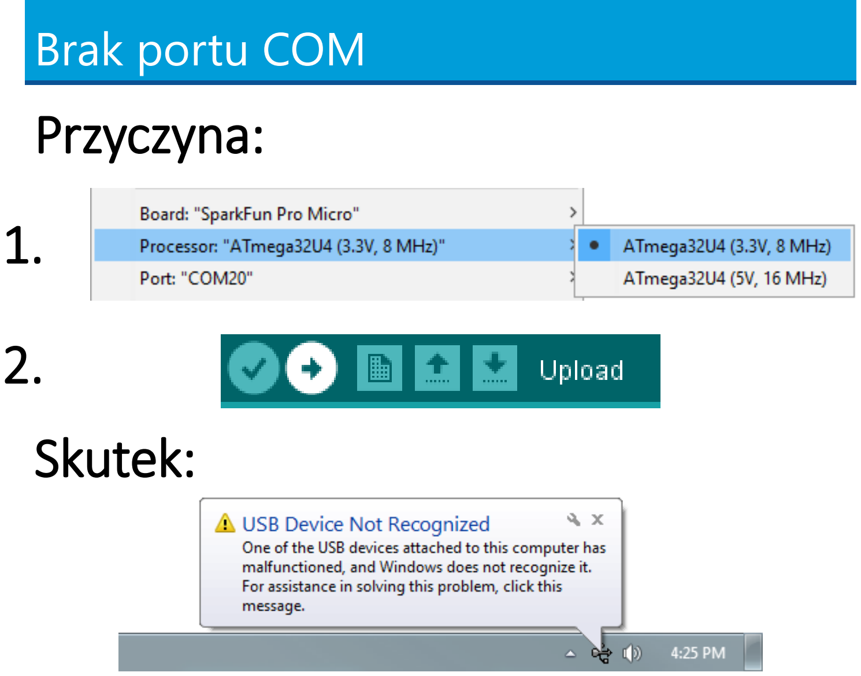
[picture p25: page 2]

Brak portu COM

1.

2.

## Skutek:

Brak portu COM – opis problemu

https://learn.sparkfun.com/tutorials/pro-micro--fio-v3-hookup-guide/troubleshooting-and-faq (https://learn.sparkfun.com/tutorials/pro-micro--fio-v3-hookup-guide/troubleshooting-and-faq)

1.

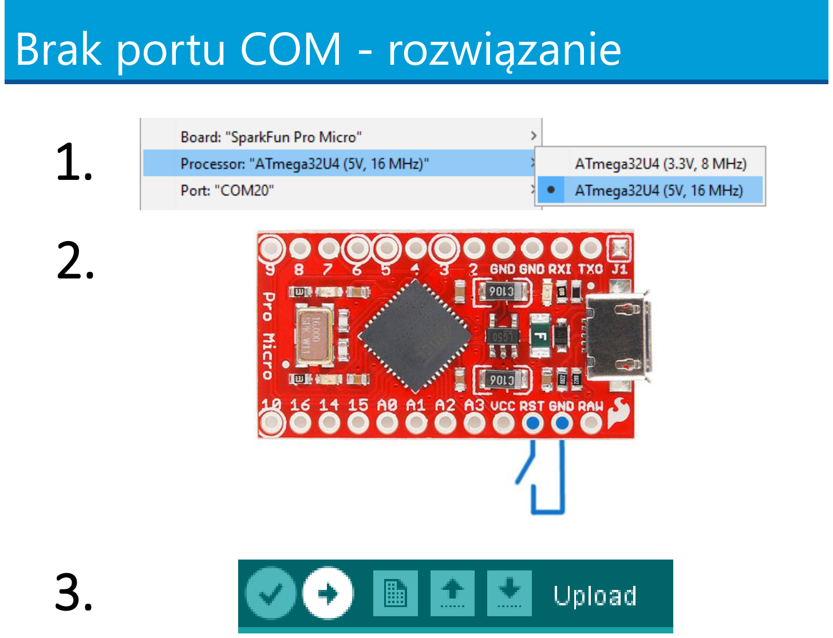
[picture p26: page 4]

Brak portu COM - rozwiązanie

2.

3.

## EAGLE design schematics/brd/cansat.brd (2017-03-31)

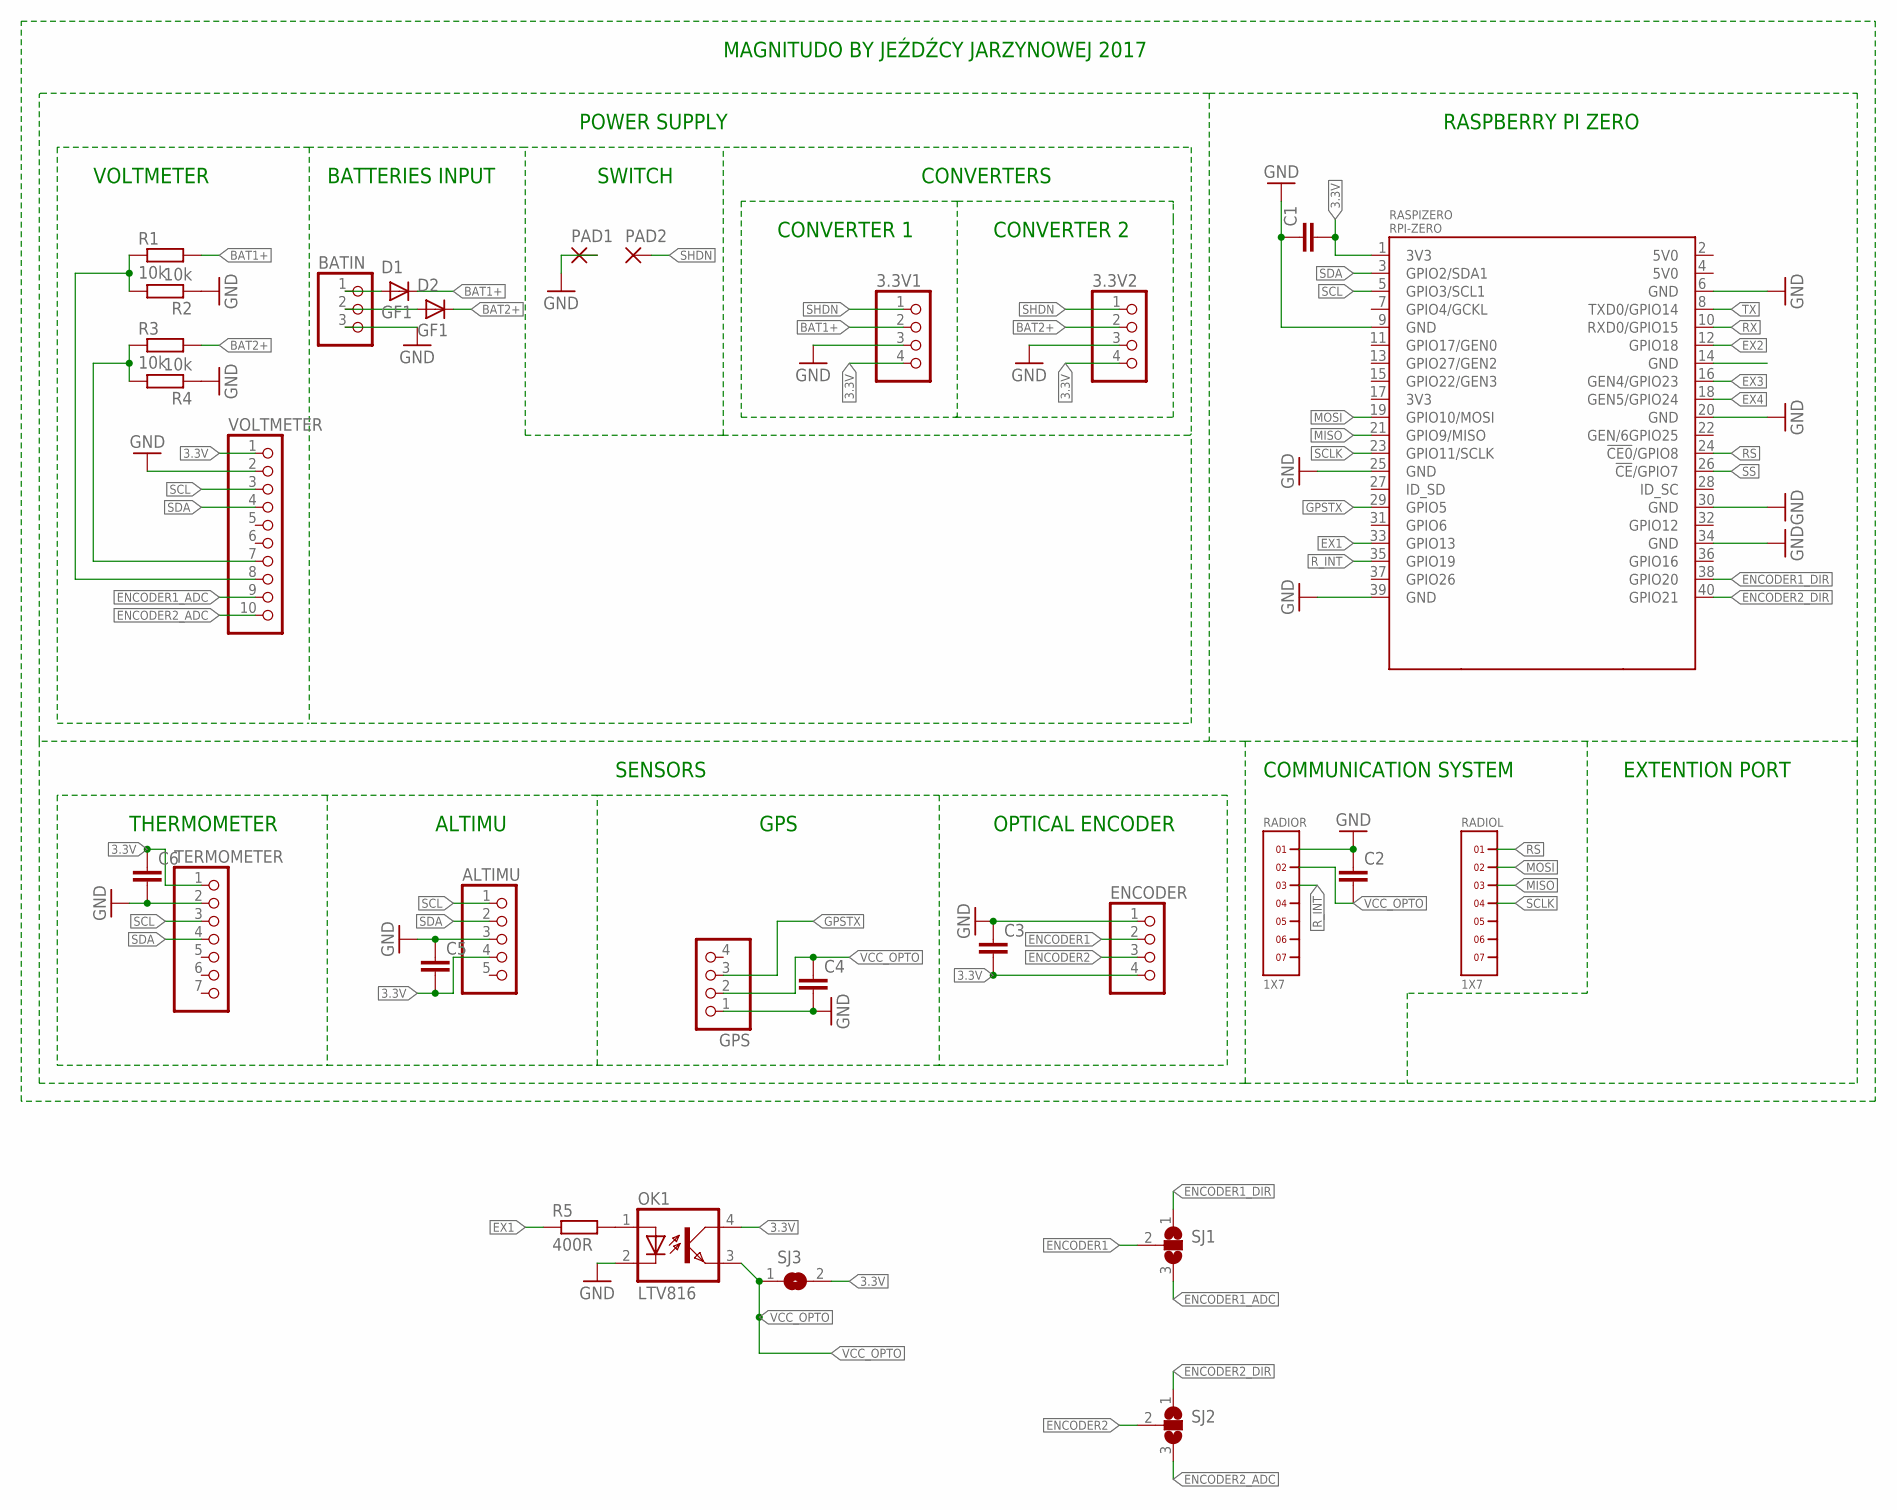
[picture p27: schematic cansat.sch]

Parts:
3.3V1, 3.3V2: PINHD-1X4; 1X04
ALTIMU: PINHD-1X5; 1X05
BATIN: PINHD-1X3; 1X03
C1, C2, C3, C4, C5, C6: CC1206; C1206
D1, D2: GF1; SMA-DO214AC
ENCODER: PINHD-1X4; 1X04
GPS: PINHD-1X4; 1X04
OK1: LTV816; DIL04
PAD1, PAD2: WIREPADSMD5-2,5; 5-2,5
R1, R2, R3, R4: 10k; R1206
R5: 400R; R1206
RADIOL: 1X7
RADIOR: 1X7
RASPIZERO: RPI-ZERO; RASPBERRYPI_BASTELSTUBE_V13_RASPI_BOARD_B+_FULL
SJ1, SJ2: SJ2W; SJ_2
SJ3: SJ
TERMOMETER: PINHD-1X7; 1X07
VOLTMETER: PINHD-1X10; 1X10

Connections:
3.3V: 3.3V1.4, 3.3V2.4, ALTIMU.4, C1.2, C3.2, C5.2, C6.1, ENCODER.4, OK1.4 (COL), RASPIZERO.1 (3V3), SJ3.2, TERMOMETER.1, VOLTMETER.1
BAT1+: 3.3V1.2, D1.K (C), R1.2
BAT2+: 3.3V2.2, D2.K (C), R3.2
ENCODER1: ENCODER.2, SJ1.2
ENCODER1_ADC: SJ1.3, VOLTMETER.9
ENCODER1_DIR: RASPIZERO.38 (GPIO20), SJ1.1
ENCODER2: ENCODER.3, SJ2.2
ENCODER2_ADC: SJ2.3, VOLTMETER.10
ENCODER2_DIR: RASPIZERO.40 (GPIO21), SJ2.1
EX1: R5.1, RASPIZERO.33 (GPIO13)
EX2: RASPIZERO.12 (GPIO18)
EX3: RASPIZERO.16 (GEN4/GPIO23)
EX4: RASPIZERO.18 (GEN5/GPIO24)
GND: 3.3V1.3, 3.3V2.3, ALTIMU.3, BATIN.3, C1.1, C2.1, C3.1, C4.2, C5.1, C6.2, ENCODER.1, GPS.1, OK1.2 (C), PAD1.1, R2.1, R4.1, RADIOR.1, RASPIZERO.6 (GND), RASPIZERO.9 (GND), RASPIZERO.20 (GND), RASPIZERO.25 (GND), RASPIZERO.30 (GND), RASPIZERO.34 (GND), RASPIZERO.39 (GND), TERMOMETER.2, VOLTMETER.2
GND@4: RASPIZERO.14 (GND)
GPSTX: GPS.3, RASPIZERO.29 (GPIO5)
MISO: RADIOL.3, RASPIZERO.21 (GPIO9/MISO)
MOSI: RADIOL.2, RASPIZERO.19 (GPIO10/MOSI)
unnamed: R1.1, R2.2, VOLTMETER.8
unnamed: OK1.1 (A), R5.2
unnamed: R3.1, R4.2, VOLTMETER.7
unnamed: BATIN.1, D1.A
unnamed: BATIN.2, D2.A
RS: RADIOL.1, RASPIZERO.24 (!CE0!/GPIO8)
RX: RASPIZERO.10 (RXD0/GPIO15)
R_INT: RADIOR.3, RASPIZERO.35 (GPIO19)
SCL: ALTIMU.1, RASPIZERO.5 (GPIO3/SCL1), TERMOMETER.3, VOLTMETER.3
SCLK: RADIOL.4, RASPIZERO.23 (GPIO11/SCLK)
SDA: ALTIMU.2, RASPIZERO.3 (GPIO2/SDA1), TERMOMETER.4, VOLTMETER.4
SHDN: 3.3V1.1, 3.3V2.1, PAD2.1
SS: RASPIZERO.26 (!CE!/GPIO7)
TX: RASPIZERO.8 (TXD0/GPIO14)
VCC_OPTO: C2.2, C4.1, GPS.2, OK1.3 (EMIT), RADIOR.2, SJ3.1

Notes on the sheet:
BATTERIES INPUT
SWITCH
POWER SUPPLY
RASPBERRY PI ZERO
CONVERTERS
CONVERTER 1
CONVERTER 2
SENSORS
COMMUNICATION SYSTEM
THERMOMETER
ALTIMU
GPS
OPTICAL ENCODER
MAGNITUDO BY JEŹDŹCY JARZYNOWEJ 2017
EXTENTION PORT
VOLTMETER

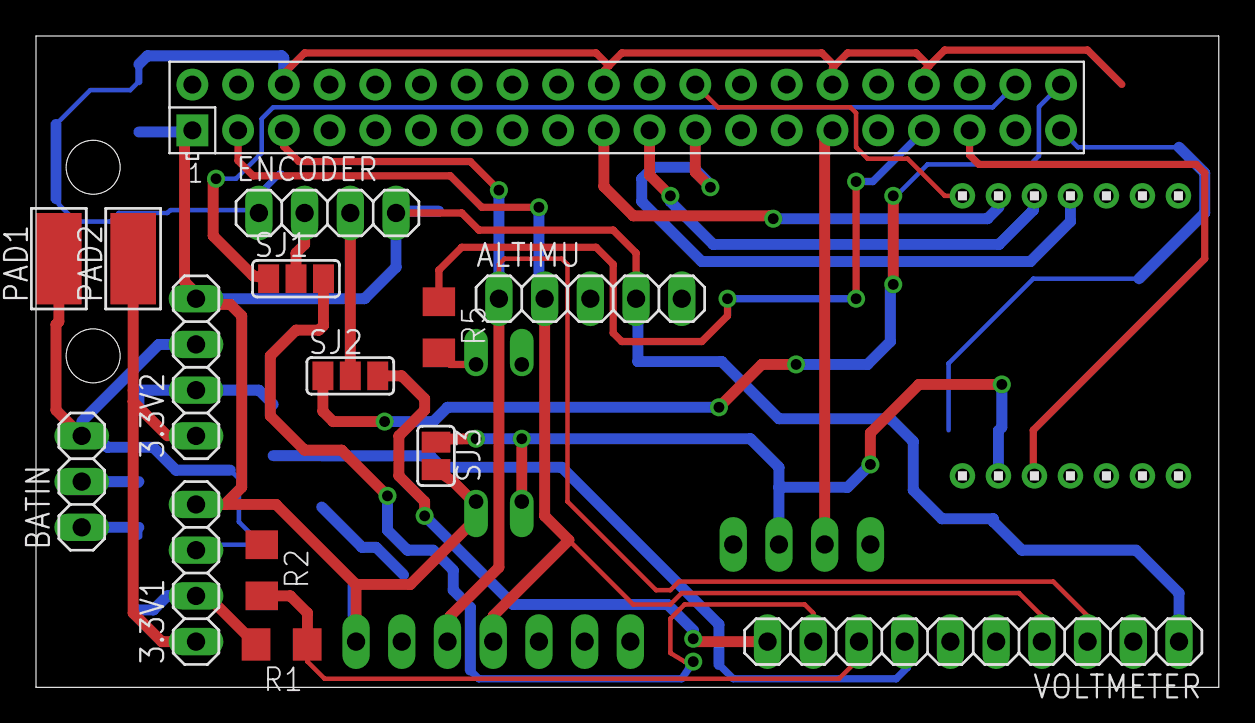
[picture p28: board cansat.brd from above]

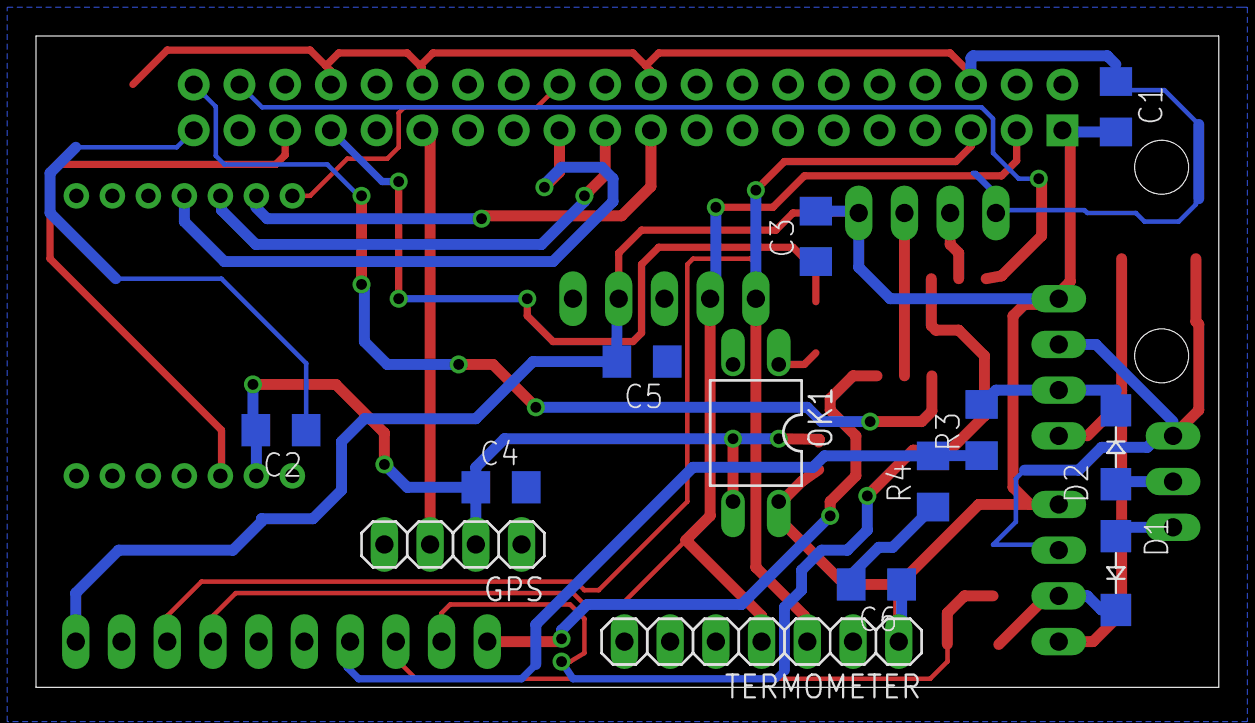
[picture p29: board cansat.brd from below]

Board: 2 copper layers, 65.7 x 36.2 mm, 30 parts (13 on the bottom side), 26 nets.

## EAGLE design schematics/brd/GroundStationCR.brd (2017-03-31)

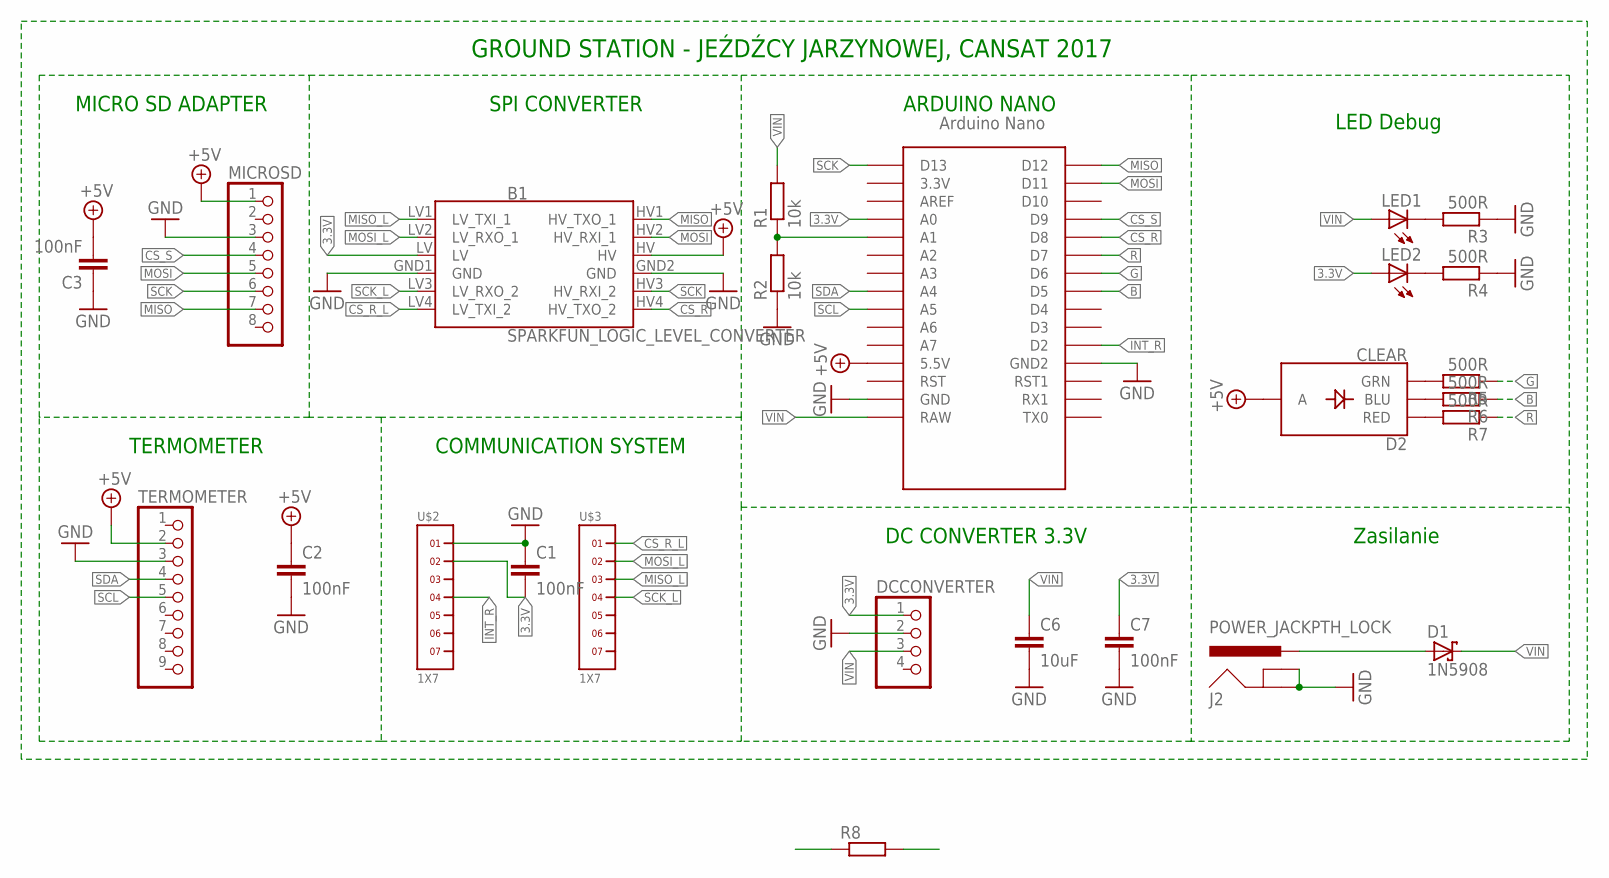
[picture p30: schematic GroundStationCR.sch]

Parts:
B1: SPARKFUN_LOGIC_LEVEL_CONVERTER
C1, C2, C3, C7: 100nF; C050-025X075
C6: 10uF; C050-025X075
D1: 1N5908; C4111-15
D2: CLEAR; LED-RGB-THRU
DCCONVERTER: PINHD-1X4; 1X04
J2: POWER_JACKPTH_LOCK; POWER_JACK_PTH_LOCK
LED1, LED2: LED3MM
MICROSD: PINHD-1X8; 1X08
R1, R2: 10k; 0207/7
R3, R4, R5, R6, R7: 500R; 0207/7
R8: R-EU_0207/5V; 0207/5V
TERMOMETER: PINHD-1X9; 1X09
U$1: NANO
U$2, U$3: 1X7

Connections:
3.3V: B1.LV, C1.2, C7.1, DCCONVERTER.1, LED2.A, U$1.A0, U$2.2
+5V: B1.HV, C2.1, C3.2, D2.2 (A), MICROSD.1, TERMOMETER.2, U$1.5V (5.5V)
B: R6.1, U$1.D5
CS_R: B1.HV4 (HV_TXO_2), U$1.D8
CS_R_L: B1.LV4 (LV_TXI_2), U$3.1
CS_S: MICROSD.4, U$1.D9
G: R5.1, U$1.D6
GND: B1.GND1 (GND), B1.GND2 (GND), C1.1, C2.2, C3.1, C6.2, C7.2, DCCONVERTER.2, J2.GND, J2.GNDBREAK, MICROSD.3, R2.1, R3.1, R4.1, TERMOMETER.3, U$1.GND, U$1.GND1 (GND2), U$2.1
INT_R: U$1.D2, U$2.4
MISO: B1.HV1 (HV_TXO_1), MICROSD.7, R8.1, R8.2, U$1.D12
MISO_L: B1.LV1 (LV_TXI_1), U$3.3
MOSI: B1.HV2 (HV_RXI_1), MICROSD.5, U$1.D11
MOSI_L: B1.LV2 (LV_RXO_1), U$3.2
unnamed: D1.A, J2.PWR
unnamed: R1.1, R2.2, U$1.A1
unnamed: LED1.K (C), R3.2
unnamed: LED2.K (C), R4.2
unnamed: D2.3 (GRN), R5.2
unnamed: D2.4 (BLU), R6.2
unnamed: D2.1 (RED), R7.2
R: R7.1, U$1.D7
SCK: B1.HV3 (HV_RXI_2), MICROSD.6, U$1.D13
SCK_L: B1.LV3 (LV_RXO_2), U$3.4
SCL: TERMOMETER.5, U$1.A5
SDA: TERMOMETER.4, U$1.A4
VIN: C6.1, D1.C, DCCONVERTER.3, LED1.A, R1.2, U$1.RAW

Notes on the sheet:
ARDUINO NANO
MICRO SD ADAPTER
TERMOMETER
COMMUNICATION SYSTEM
DC CONVERTER 3.3V
GROUND STATION - JEŹDŹCY JARZYNOWEJ, CANSAT 2017
SPI CONVERTER
Zasilanie
LED Debug

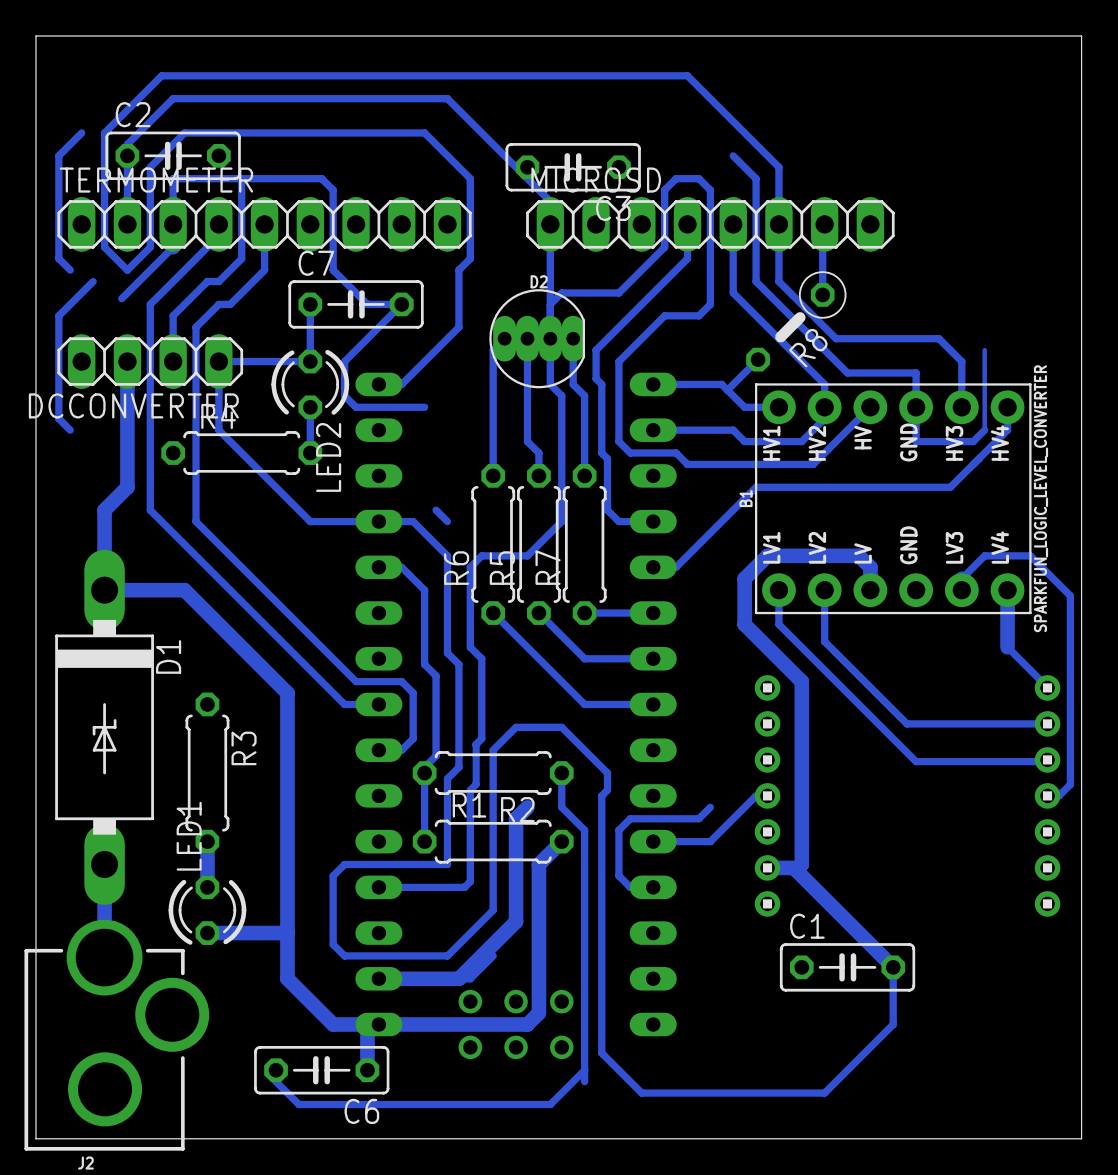
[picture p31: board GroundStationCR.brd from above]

Board: 2 copper layers, 58.1 x 61.3 mm, 25 parts (0 on the bottom side), 26 nets.

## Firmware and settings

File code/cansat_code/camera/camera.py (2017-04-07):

#!/usr/bin/python

from picamera import PiCamera
from time import sleep
camera = PiCamera()
camera.resolution = (3280, 2464)

while True:
    file_last_read = open('/home/pi/data/camera/last_read_number.txt', 'r+')
    last_read = int(file_last_read.read())
    file_last_read.close()
    read = last_read + 1
    camera.capture('/home/pi/data/camera/image{0:04d}.jpg'.format(read))
    file_last_read = open('/home/pi/data/camera/last_read_number.txt', 'w')
    file_last_read.write(str(read))
    file_last_read.close()
    sleep (10)

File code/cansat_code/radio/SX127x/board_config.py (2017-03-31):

""" Defines the BOARD class that contains the board pin mappings. """

# Copyright 2015 Mayer Analytics Ltd.
#
# This file is part of pySX127x.
#
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
# You can be released from the requirements of the license by obtaining a commercial license. Such a license is
# mandatory as soon as you develop commercial activities involving pySX127x without disclosing the source code of your
# own applications, or shipping pySX127x with a closed source product.
#
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

import RPi.GPIO as GPIO
import spidev

import time


class BOARD:
    """ Board initialisation/teardown and pin configuration is kept here.
        This is the Raspberry Pi board with one LED and a modtronix inAir9B
    """
    # Note that the BCOM numbering for the GPIOs is used.
    DIO0 = 19   # RaspPi GPIO 19
    DIO1 = 23   # RaspPi GPIO 23
    DIO2 = 24   # RaspPi GPIO 24
    DIO3 = 25   # RaspPi GPIO 25
    LED  = 18   # RaspPi GPIO 18 connects to the LED on the proto shield
    SWITCH = 4  # RaspPi GPIO 4 connects to a switch

    # The spi object is kept here
    spi = None

    @staticmethod
    def setup():
        """ Configure the Raspberry GPIOs
        :rtype : None
        """
        GPIO.setmode(GPIO.BCM)
        # LED
        #GPIO.setup(BOARD.LED, GPIO.OUT)
        #GPIO.output(BOARD.LED, 0)
        # switch
        GPIO.setup(BOARD.SWITCH, GPIO.IN, pull_up_down=GPIO.PUD_DOWN) 
        # DIOx
        for gpio_pin in [BOARD.DIO0, BOARD.DIO1, BOARD.DIO2, BOARD.DIO3]:
            GPIO.setup(gpio_pin, GPIO.IN, pull_up_down=GPIO.PUD_DOWN)


    @staticmethod
    def teardown():
        """ Cleanup GPIO and SpiDev """
        GPIO.cleanup()
        BOARD.spi.close()

    @staticmethod
    def SpiDev(spi_bus=0, spi_cs=0):
        """ Init and return the SpiDev object
        :return: SpiDev object
        :param spi_bus: The RPi SPI bus to use: 0 or 1
        :param spi_cs: The RPi SPI chip select to use: 0 or 1
        :rtype: SpiDev
        """
        BOARD.spi = spidev.SpiDev()
        BOARD.spi.open(spi_bus, spi_cs)
        return BOARD.spi

    @staticmethod
    def add_event_detect(dio_number, callback):
        """ Wraps around the GPIO.add_event_detect function
        :param dio_number: DIO pin 0...5
        :param callback: The function to call when the DIO triggers an IRQ.
        :return: None
        """
        GPIO.add_event_detect(dio_number, GPIO.RISING, callback=callback)

    @staticmethod
    def add_events(cb_dio0, cb_dio1, cb_dio2, cb_dio3, cb_dio4, cb_dio5, switch_cb=None):
        BOARD.add_event_detect(BOARD.DIO0, callback=cb_dio0)
        BOARD.add_event_detect(BOARD.DIO1, callback=cb_dio1)
        BOARD.add_event_detect(BOARD.DIO2, callback=cb_dio2)
        BOARD.add_event_detect(BOARD.DIO3, callback=cb_dio3)
        # the modtronix inAir9B does not expose DIO4 and DIO5
        if switch_cb is not None:
            GPIO.add_event_detect(BOARD.SWITCH, GPIO.RISING, callback=switch_cb, bouncetime=300)

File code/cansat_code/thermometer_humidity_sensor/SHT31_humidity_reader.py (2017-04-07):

#!/usr/bin/python

from SHT31 import *
from datetime import datetime
import time
file_datetable = open('/home/pi/data/humidity/datetable.txt', 'a')
while True:
        file_last_read = open('/home/pi/data/humidity/last_read_number.txt', 'r+')
        last_read = int(file_last_read.read())
        file_last_read.close()
        read=last_read+1
        file_output = open('/home/pi/data/humidity/'+str(read), 'w')
        file_output.write(str(read_humidity()))
        file_output.close()
        file_last_read = open('/home/pi/data/humidity/last_read_number.txt', 'w')
        file_last_read.write(str(read))
        file_last_read.close()
        file_datetable.write(str(read)+','+datetime.now().strftime('%Y,%m,%d,%H,%M,%S')+'\n')
###     uncomment next line for less data flow  ###
        time.sleep(1)

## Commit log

2016-12-07 working(almost) thermometer-module prototype
2017-02-17 removed empty files, added simple temperature/humidity read implementation from Adafruit driver. declared temperature_read() returning temperature in deg C and humidity_read() in %
2017-02-19 Changes to be committed: new file: altimu/altimu.py new file: altimu/altimu.pyc new file: altimu/functions.py new file: altimu/functions.pyc new file: thermometer_humidity_sensor/Adafruit_SHT31.pyc n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
2017-02-19 Implemented main loop and data flushout directly in python Current speed accessible is about 10Hz
    Changes to be committed:
    modified: Adafruit_SHT31.pyc
    modified: SHT31.pyc
    modified: SHT31_humidity_reader.py
    new file: SHT31_humidity_reader.sh
    modified: SHT31_temperature_reader.py
    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
2017-02-19 First tests of IMU using nice library found on github. test2.py works, gotta figure out data meaning.
2017-02-21 Found working LoRa library. Tested and performed well with 5 short transmits per second. Base for future development.
    [LoRaArgumentParser.py, board_config.py]
2017-02-23 Changes not staged for commit: modified: test.py deleted: test2.py
2017-02-26 schematics files
    schematics of the ground station & cansat
    [GroundStationCR-old.brd, GroundStationCR.sch, cansat.sch]
2017-02-26 minor fixes
    [GroundStationCR.brd, GroundStationCR.sch]
2017-02-26 minor changes
    minor changes
    [GroundStationvpatryk.brd, GroundStationvpatryk.sch]
2017-02-27 cansat main board
    [cansat.brd, cansat.sch]
2017-02-28 Changed CR, made it work. Found out buggy TXes were hardware issue, 100uF capacitor @ radio power supply fixed them well.
2017-02-28 removed LED support causing warnings to sys stdout
2017-02-28 cansat board fixed
    [cansat.brd, cansat.sch]
2017-03-01 optocoupler on radio/gps vcc
    [cansat.brd, cansat.sch]
2017-03-06 rm'ed old sh scripts, surpressed data flow
2017-03-07 improved overall stability with file closing
    [SHT31_humidity_reader.py, SHT31_temperature_reader.py]
2017-03-22 New battery voltage reading function
2017-03-22 added voltage support
2017-03-23 wind-speed sensor driver
2017-03-23 added new sensors based on ADC
2017-04-04 Meh, connected it directly to dedicated UART
2017-04-05 camera service
2017-04-05 camera support

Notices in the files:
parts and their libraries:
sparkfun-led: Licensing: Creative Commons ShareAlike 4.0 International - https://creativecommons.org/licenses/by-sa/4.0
